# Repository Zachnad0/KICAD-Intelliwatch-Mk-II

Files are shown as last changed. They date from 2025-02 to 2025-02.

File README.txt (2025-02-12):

Intelliwatch Mk II

=== Operational Features ===
Internet Connection Required:
	Update internal date & time (automatic, whenever connection established)
	Obtain and display current stock values (manual update request)
	(?? google API) Show next #n google calendar events (A/B scroll up/down)
	(?? do last if at all) Google tasks integration (manual update request)
	Show weather for next 24 hours, very simple (mode, A/B scroll left/right)

Functions & Software Modes:
	Toggle time 7-seg disp. by displaying no digits (mode, A/B key)
	[X] replaced by switch - "off-mode" of LCD display (just a mode, makes LCD LED pin switch by p-MOS)
	QMC5883L Compass Mode shows current heading (mode, A/B keys change inclination temporarily, but that is not saved)
	ADC voltmeter/osc-scope (mode)
	(?? SD-card reading must be used) Cat Picture Mode cycle through pics on SD card (mode, A/B change pic)
	Torch Mode (A/B key inc/dec brightness in 3 steps, auto turn off on mode change)

=== Main Specs ===
Supply voltage: 
	>> Standard DC Barrel Jack << (can connect to any >=6V supply effectively)
	Seperate unit containing 2-4x 3.7V Li-ion rechargeable cells

Visual Displays and Indicators:
	1.8'' TFT LCD display (I2C)
	4-digit 7-segment display (I2C)
	SMD LEDs in series with keyswitches, and more for power and etc.

Controls:
	4x cherry-mx keyswitches
	standard power switch

=== Mk III+ Possible Features ===
Resistance Measuring Mode!!! color bands as rectangles on LCD (mode, A/B shows raw/E12)
Digitally-tuned radio receiver?
Mains AC power in (dangerous???)
Li-Ion cells charging circuit and 12V DC cable power in.
Snapper Card Holder/deployer??? (mode, A/B extend/retract)

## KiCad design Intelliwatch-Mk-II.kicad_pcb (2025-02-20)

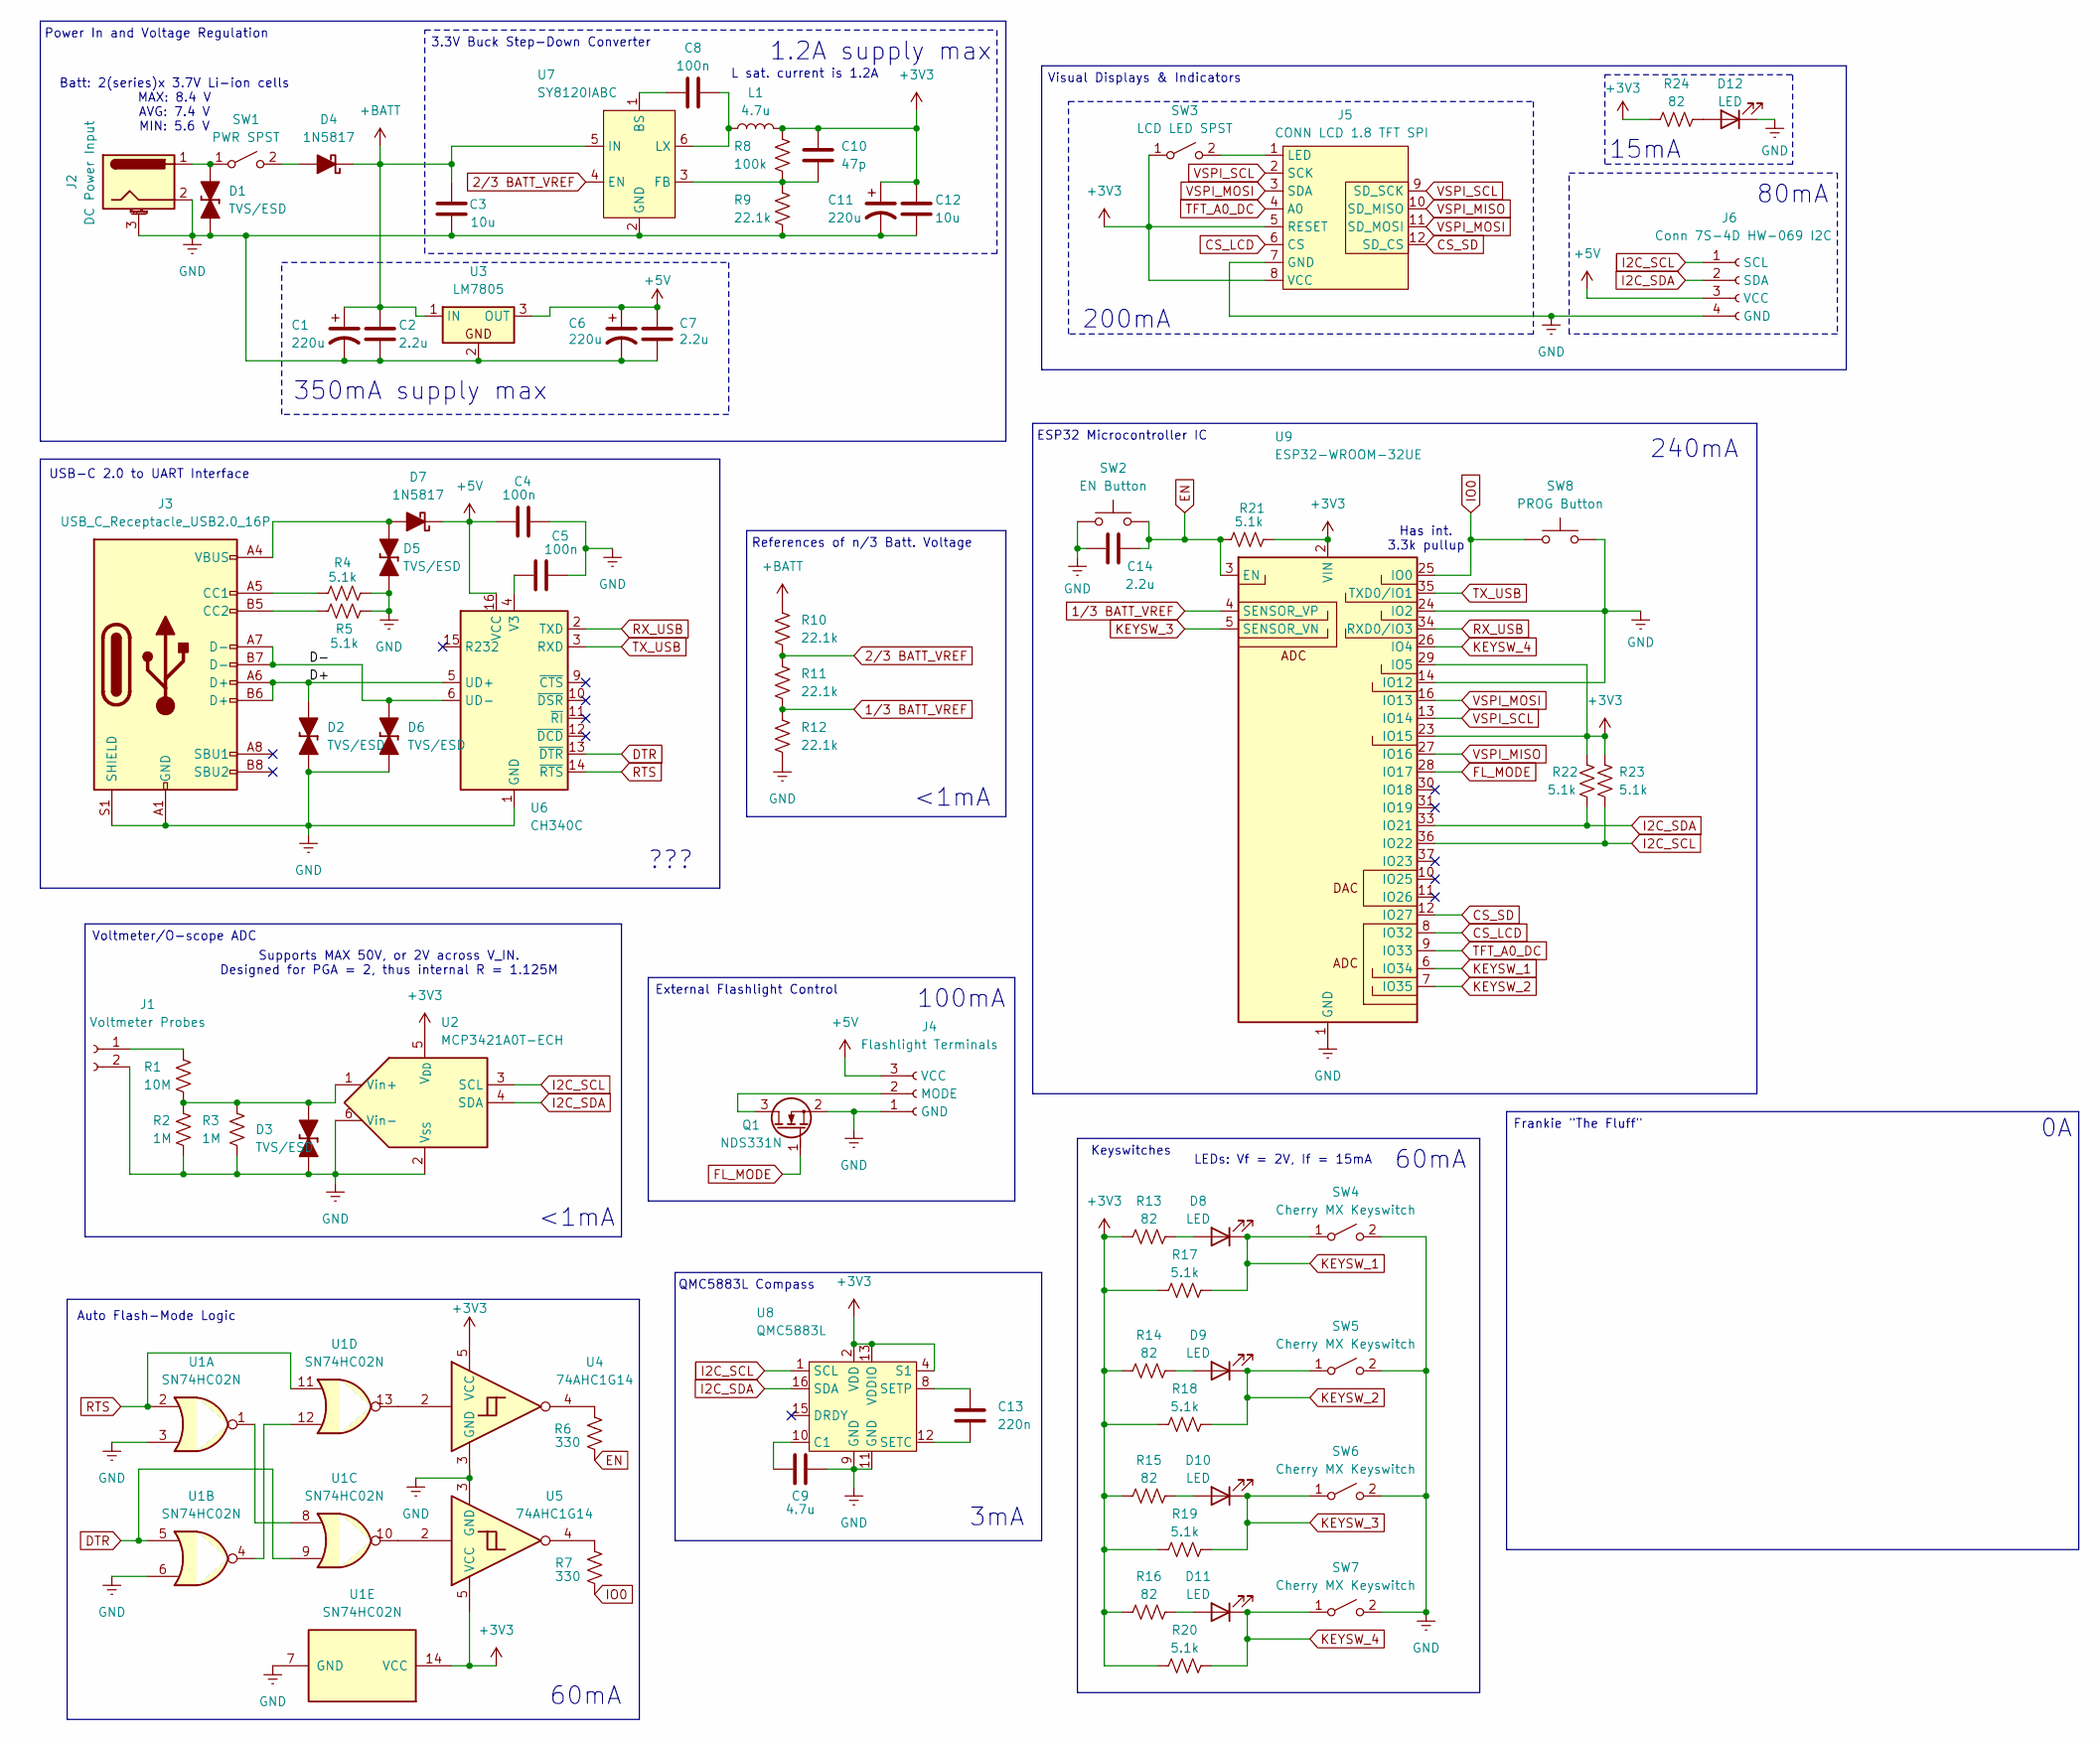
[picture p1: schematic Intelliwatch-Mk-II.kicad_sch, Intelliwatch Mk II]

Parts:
C1, C6, C11: 220u; CP_Radial_D6.3mm_P2.50mm; LCSC Part # n/a
C2, C7, C14: 2.2u; C_0603_1608Metric; LCSC Part # C415535
C3, C12: 10u; C_0805_2012Metric; LCSC Part # C440198
C4, C5, C8: 100n; C_1206_3216Metric; LCSC Part # C97946
C9: 4.7u; C_0805_2012Metric; LCSC Part # C437557
C10: 47p; C_0603_1608Metric; LCSC Part # C882552
C13: 220n; C_1206_3216Metric; LCSC Part # C161277
D1, D2, D3, D5, D6: TVS/ESD; D_SOD-323_TVS; LCSC Part # C5180217
D4, D7: 1N5817; D_A-405_P10.16mm_Horizontal; LCSC Part # n/a
D8, D9, D10, D11, D12: LED; LED_0603_1608Metric; LCSC Part # C497928
J1: Voltmeter Probes; Standard IO Holes; LCSC Part # n/a
J2: DC Power Input; BarrelJack_Horizontal; LCSC Part # C720557
J3: USB_C_Receptacle_USB2.0_16P; USB_C_Receptacle_G-Switch_GT-USB-7010ASV; LCSC Part # C2988369
J4: Flashlight Terminals; PinSocket_1x03_P2.54mm_Vertical; LCSC Part # n/a
J5: CONN LCD 1.8 TFT SPI; Conn 1.8 TFT LCD SPI; LCSC Part # n/a
J6: Conn 7S-4D HW-069 I2C; LCSC Part # n/a
L1: 4.7u; L_7.3x7.3_H3.5; LCSC Part # C136201
Q1: NDS331N; SuperSOT-3; LCSC Part # C192741
R1: 10M; Fav Res Axial 10.16mm; LCSC Part # C5200509
R2, R3: 1M; Fav Res Axial 10.16mm; LCSC Part # n/a
R4, R5, R17, R18, R19, R20, R21, R22, R23: 5.1k; R_0603_1608Metric; LCSC Part # C318133
R6, R7: 330; R_0603_1608Metric; LCSC Part # C384242
R8: 100k; R_0603_1608Metric; LCSC Part # C25803
R9, R10, R11, R12: 22.1k; R_0603_1608Metric; LCSC Part # C5382621
R13, R14, R15, R16, R24: 82; R_0603_1608Metric; LCSC Part # C861575
SW1: PWR SPST; Standard IO Holes; LCSC Part # n/a
SW2: EN Button; SW_101-C-W_XKB; LCSC Part # C318938
SW3: LCD LED SPST; Standard IO Holes; LCSC Part # n/a
SW4, SW5, SW6, SW7: Cherry MX Keyswitch; SW_Cherry_MX_1.00u_Plate; LCSC Part # n/a
SW8: PROG Button; SW_101-C-W_XKB; LCSC Part # C318938
U1: SN74HC02N; DIP-14_W7.62mm; LCSC Part # C2897
U2: MCP3421A0T-ECH; SOT-23-6; LCSC Part # C29454
U3: LM7805; TO-220-3_Vertical; LCSC Part # n/a
U4, U5: 74AHC1G14; SOT-353_SC-70-5_BigPads; LCSC Part # C3272823
U6: CH340C; SOP-16_4.55x10.3mm_P1.27mm; LCSC Part # C84681
U7: SY8120IABC; SOT-23-6; LCSC Part # C479076
U8: QMC5883L; LGA-16_3x3mm_P0.5mm; LCSC Part # C976032
U9: ESP32-WROOM-32UE; LCSC Part # C701346

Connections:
1/3 BATT_VREF: R11.2, R12.1, U9.4 (SENSOR_VP)
2/3 BATT_VREF: R10.2, R11.1, U7.4 (EN)
+3V3: C10.1, C11.1, C12.1, J5.5 (RESET), J5.8 (VCC), L1.2, R8.1, R13.2, R14.2, R15.2, R16.2, R17.2, R18.2, R19.2, R20.2, R21.1, R22.1, R23.1, R24.1, SW3.1 (A), U1.14 (VCC), U2.5 (V_{DD}), U4.5 (VCC), U5.5 (VCC), U8.2 (VDD), U8.4 (S1), U8.13 (VDDIO), U9.2 (VIN), U9.23 (IO15), U9.29 (IO5)
+5V: C4.1, C6.1, C7.1, D7.1 (K), J4.3 (VCC), J6.3 (VCC), U3.3 (OUT), U6.16 (VCC)
+BATT: C1.1, C2.1, C3.1, D4.1 (K), R10.1, U3.1 (IN), U7.5 (IN)
/D+: D2.1 (K), J3.A6 (D+), J3.B6 (D+), U6.5 (UD+)
/D-: D6.1 (K), J3.A7 (D-), J3.B7 (D-), U6.6 (UD-)
CS_LCD: J5.6 (CS), U9.8 (IO32)
CS_SD: J5.12 (SD_CS), U9.12 (IO27)
DTR: U1.5, U1.9, U6.13 (~DTR)
EN: C14.1, R6.1, R21.2, SW2.2, U9.3 (EN)
FL_MODE: Q1.1 (G), U9.28 (IO17)
GND: C1.2, C2.2, C3.2, C4.2, C5.2, C6.2, C7.2, C9.2, C11.2, C12.2, C14.2, D1.2 (A), D2.2 (A), D3.2 (A), D5.2 (A), D6.2 (A), D12.1 (K), J1.2, J2.2, J2.3 (MountPin), J3.A1 (GND), J3.A12 (GND), J3.B1 (GND), J3.B12 (GND), J3.S1 (SHIELD), J4.1 (GND), J5.7 (GND), J6.4 (GND), Q1.2 (S), R2.2, R3.2, R4.2, R5.2, R9.2, R12.2, SW2.1, SW4.2 (B), SW5.2 (B), SW6.2 (B), SW7.2 (B), SW8.2, U1.3, U1.6, U1.7 (GND), U2.2 (V_{SS}), U2.6 (Vin-), U3.2, U4.3 (GND), U5.3 (GND), U6.1 (GND), U7.2 (GND), U8.9 (GND), U8.11 (GND), U9.1 (GND), U9.14 (IO12), U9.15 (GND), U9.24 (IO2), U9.38 (GND), U9.39 (GND)
I2C_SCL: J6.1 (SCL), R23.2, U2.3 (SCL), U8.1 (SCL), U9.36 (IO22)
I2C_SDA: J6.2 (SDA), R22.2, U2.4 (SDA), U8.16 (SDA), U9.33 (IO21)
IO0: R7.2, SW8.1, U9.25 (IO0)
KEYSW_1: D8.1 (K), R17.1, SW4.1 (A), U9.6 (IO34)
KEYSW_2: D9.1 (K), R18.1, SW5.1 (A), U9.7 (IO35)
KEYSW_3: D10.1 (K), R19.1, SW6.1 (A), U9.5 (SENSOR_VN)
KEYSW_4: D11.1 (K), R20.1, SW7.1 (A), U9.26 (IO4)
unnamed: D1.1 (K), J2.1, SW1.1 (A)
unnamed: D3.1 (K), R1.1, R2.1, R3.1, U2.1 (Vin+)
unnamed: D4.2 (A), SW1.2 (B)
unnamed: D5.1 (K), D7.2 (A), J3.A4 (VBUS), J3.A9 (VBUS), J3.B4 (VBUS), J3.B9 (VBUS)
unnamed: D8.2 (A), R13.1
unnamed: D9.2 (A), R14.1
unnamed: D10.2 (A), R15.1
unnamed: D11.2 (A), R16.1
unnamed: D12.2 (A), R24.2
unnamed: J1.1, R1.2
unnamed: J3.A5 (CC1), R4.1
unnamed: J3.B5 (CC2), R5.1
unnamed: J4.2 (MODE), Q1.3 (D)
unnamed: J5.1 (LED), SW3.2 (B)
unnamed: R6.2, U4.4
unnamed: R7.1, U5.4
unnamed: U1.1, U1.8
unnamed: U1.10, U5.2
unnamed: U1.4, U1.12
unnamed: U1.13, U4.2
unnamed: C5.1, U6.4 (V3)
unnamed: C8.1, U7.1 (BS)
unnamed: C10.2, R8.2, R9.1, U7.3 (FB)
unnamed: C8.2, L1.1, U7.6 (LX)
unnamed: C9.1, U8.10 (C1)
unnamed: C13.2, U8.12 (SETC)
unnamed: C13.1, U8.8 (SETP)
RTS: U1.2, U1.11, U6.14 (~RTS)
RX_USB: U6.2 (TXD), U9.34 (RXD0/IO3)
TFT_A0_DC: J5.4 (A0), U9.9 (IO33)
TX_USB: U6.3 (RXD), U9.35 (TXD0/IO1)
VSPI_MISO: J5.10 (SD_MISO), U9.27 (IO16)
VSPI_MOSI: J5.3 (SDA), J5.11 (SD_MOSI), U9.16 (IO13)
VSPI_SCL: J5.2 (SCK), J5.9 (SD_SCK), U9.13 (IO14)

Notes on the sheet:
Power In and Voltage Regulation
Batt: 2(series)x 3.7V Li-ion cells MAX: 8.4 V AVG: 7.4 V MIN: 5.6 V
60mA
Voltmeter/O-scope ADC
240mA
References of n/3 Batt. Voltage
350mA supply max
200mA
ESP32 Microcontroller IC
Visual Displays & Indicators
100mA
L sat. current is 1.2A
Auto Flash-Mode Logic
Supports MAX 50V, or 2V across V_IN. Designed for PGA = 2, thus internal R = 1.125M
80mA
LEDs: Vf = 2V, If = 15mA
15mA
USB-C 2.0 to UART Interface
1.2A supply max
???
<1mA
3.3V Buck Step-Down Converter
<1mA
Keyswitches
Frankie "The Fluff"
3mA
Has int. 3.3k pullup
External Flashlight Control
QMC5883L Compass

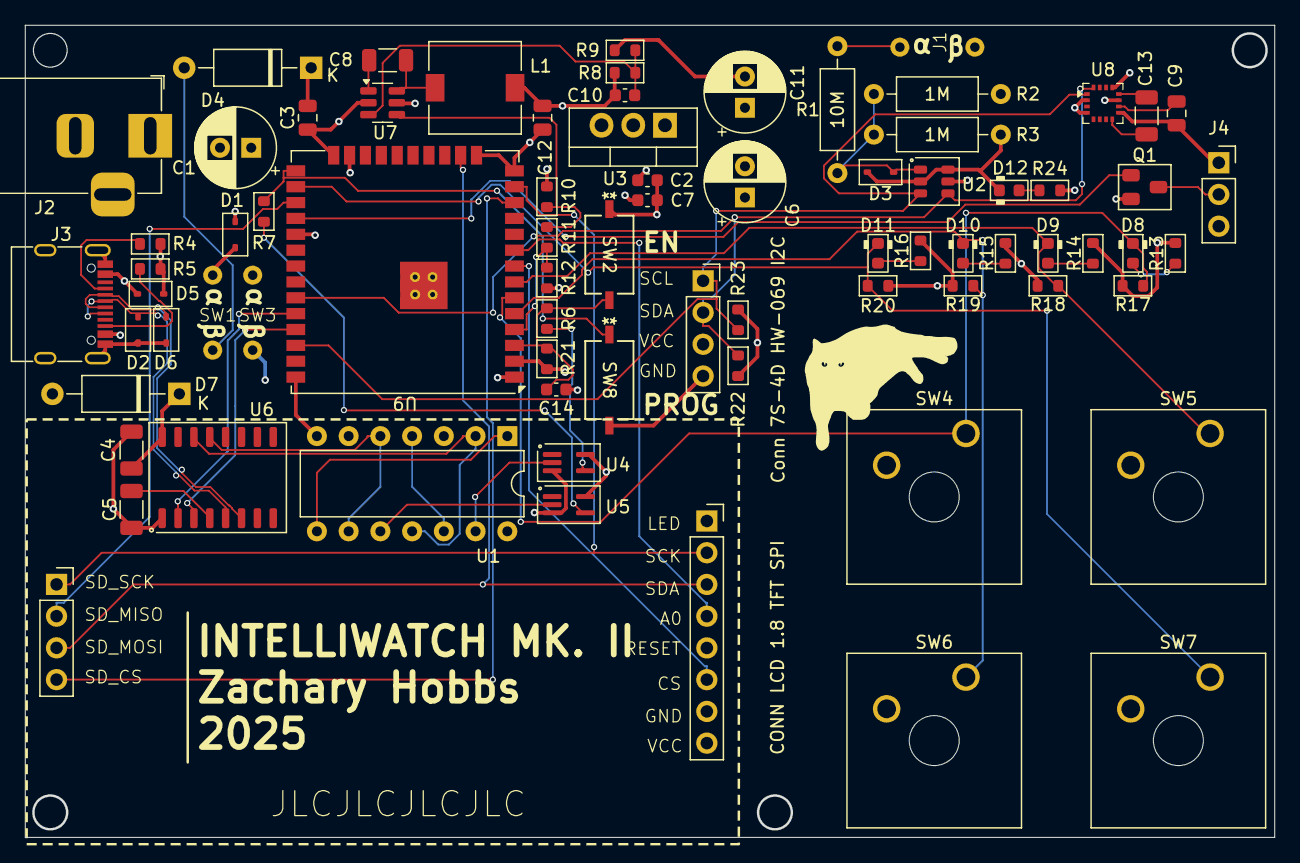
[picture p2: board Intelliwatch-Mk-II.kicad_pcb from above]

Board: 4 copper layers, 100.0 x 65.0 mm, 75 parts (0 on the bottom side), 54 nets.

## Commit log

2024-11-15 Project files initialized
    [Intelliwatch-Mk-II.kicad_pcb, Intelliwatch-Mk-II.kicad_sch]
2024-11-23 ADDED README.txt containing plan for features and etcetera
    [Intelliwatch-Mk-II.kicad_sch]
2024-11-29 WIP op-amp voltage comparator for battery level checking
    [Intelliwatch-Mk-II.kicad_sch]
2024-12-31 connected USB-C to SERIAL-UART adapter.
    [Intelliwatch-Mk-II.kicad_sch]
2025-01-02 ADDED QMC5883L IC, imported, then assigned some footprints
    [Intelliwatch-Mk-II.kicad_sch]
2025-01-16 Made capacitor values more uniform. TODO is add auto-flash support from DTR and RTS pins on SERIAL-UART converter IC.
    [Intelliwatch-Mk-II.kicad_sch]
2025-01-20 ADDED all the damn logic for automatically pulling the EN and IO0 pins into flash-mode on the ESP32 depending on RTS and DTR serial signals.
    [Intelliwatch-Mk-II.kicad_sch]
2025-01-22 ADDED cap to EN pin. ADDED 1.8 TFT SPI LCD with p-MOS on LED pin. TODO connect correct GPIOs to the SPI LCD
    [Intelliwatch-Mk-II.kicad_sch]
2025-01-24 ADDED connections to both visual displays.
    [Intelliwatch-Mk-II.kicad_sch]
2025-01-26 ADDED keyswitches and found 0603 SMD LED to be used for all other indicators in the project. ADDED connections to MOSFETs too. TODO connect keyswitch outputs to ESP32 GPIO pins.
    [Intelliwatch-Mk-II.kicad_sch]
2025-02-01 ADDED current draw for each component. ADDED flashlight. WIP TODO is sort out whether or not to re-use VSPI MOSI and SCL pins with both LCD and SD card.
    [Intelliwatch-Mk-II.kicad_sch]
2025-02-04 ADDED ADC for voltmeter/o-scope (NO res-measuring in this one). WIP TODO is determine whether or not SD and LCD will share SPI bus. TODO change voltage regulators to IC-controller buck converters.
    [Intelliwatch-Mk-II.kicad_sch]
2025-02-04 ADDED 3.3V step-down switching regulator (buck converter). TODO delete old power setup, but keep 5V regulator because that has low maximum short-term current draw so it's fine.
    [Intelliwatch-Mk-II.kicad_sch]
2025-02-05 ADDED ESD protection diodes. FIXED power supply and voltage regulation. WIP figuring out if shared SPI bus is possible.
    [Intelliwatch-Mk-II.kicad_sch]
2025-02-07 FIXED an ESD diode in the wrong place. ADDED Fluff. MODIFIED drawing sheet. REMOVED extra HSPI bus since SD and LCD can take turns using VSPI. ADDED LCSC Part # field for components.
    [Intelliwatch-Mk-II.kicad_sch]
2025-02-08 WIP adding LCSC Part # fields to parts
    [Intelliwatch-Mk-II.kicad_sch]
2025-02-09 ADDED LCSC part #s for all applicable components except for resistors. TODO WIP add resistor LCSC part #s.
    [Intelliwatch-Mk-II.kicad_sch]
2025-02-10 WIP TODO TFT LCD footprint. ADDED remaining LCSC part numbers. ADDED all basic setup specs and design rules for PCB. TODO is to arrange then route PCB, adding necessary 2.7mm diameter bolt holes.
    [Intelliwatch-Mk-II.kicad_pcb, Intelliwatch-Mk-II.kicad_sch]
2025-02-11 ADDED TFT LCD footprint w/clearance. FIXED trace width and clearance. TODO arrange PCB.
    [Intelliwatch-Mk-II.kicad_pcb, Intelliwatch-Mk-II.kicad_sch]
2025-02-12 FIXED board dimensions to be within minimum to avoid engineering fee. ADDED traces and copper areas for all power/ground nets. TODO is connecting signal lines, and maybe try using that autorouter plu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
    [Intelliwatch-Mk-II.kicad_pcb, Intelliwatch-Mk-II.kicad_sch]
2025-02-14 FIXED ESD/TVS diodes to be a different part with practically identical specs.
    [Intelliwatch-Mk-II-B_Cu.gbr, Intelliwatch-Mk-II-B_Mask.gbr, Intelliwatch-Mk-II-B_Paste.gbp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]
2025-02-20 UPDATED project to KiCad 9
    [Intelliwatch-Mk-II.kicad_pcb, Intelliwatch-Mk-II.kicad_sch]
2025-04-14 Generated interactive BOM
